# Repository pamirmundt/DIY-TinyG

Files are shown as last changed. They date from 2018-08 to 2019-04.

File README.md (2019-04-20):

# DIY TinyG
## DIY TinyG with Original Dimensions
This version has the original board dimensions and connector positions. 1206 package is selected for resistors and caps for easy hand soldering. Other than board dimensions and connector positions, rest of the components' positions are not exact.

- [X] Eagle Schmatic and Board File
- [ ] Bill of Materials
- [ ] Tested and Working

## DIY TinyG with Optimised Dimensions (100x100mm)
This version does **not** have the original board dimensions and connector positions. There is a relatively big price difference between *105x101mm* and *100x100mm* board dimensions at Seeed, OSH, JLCPCB and etc. So this version is a bit trimmed.

- [ ] Eagle Schmatic and Board File
- [ ] Bill of Materials
- [ ] Tested and Working

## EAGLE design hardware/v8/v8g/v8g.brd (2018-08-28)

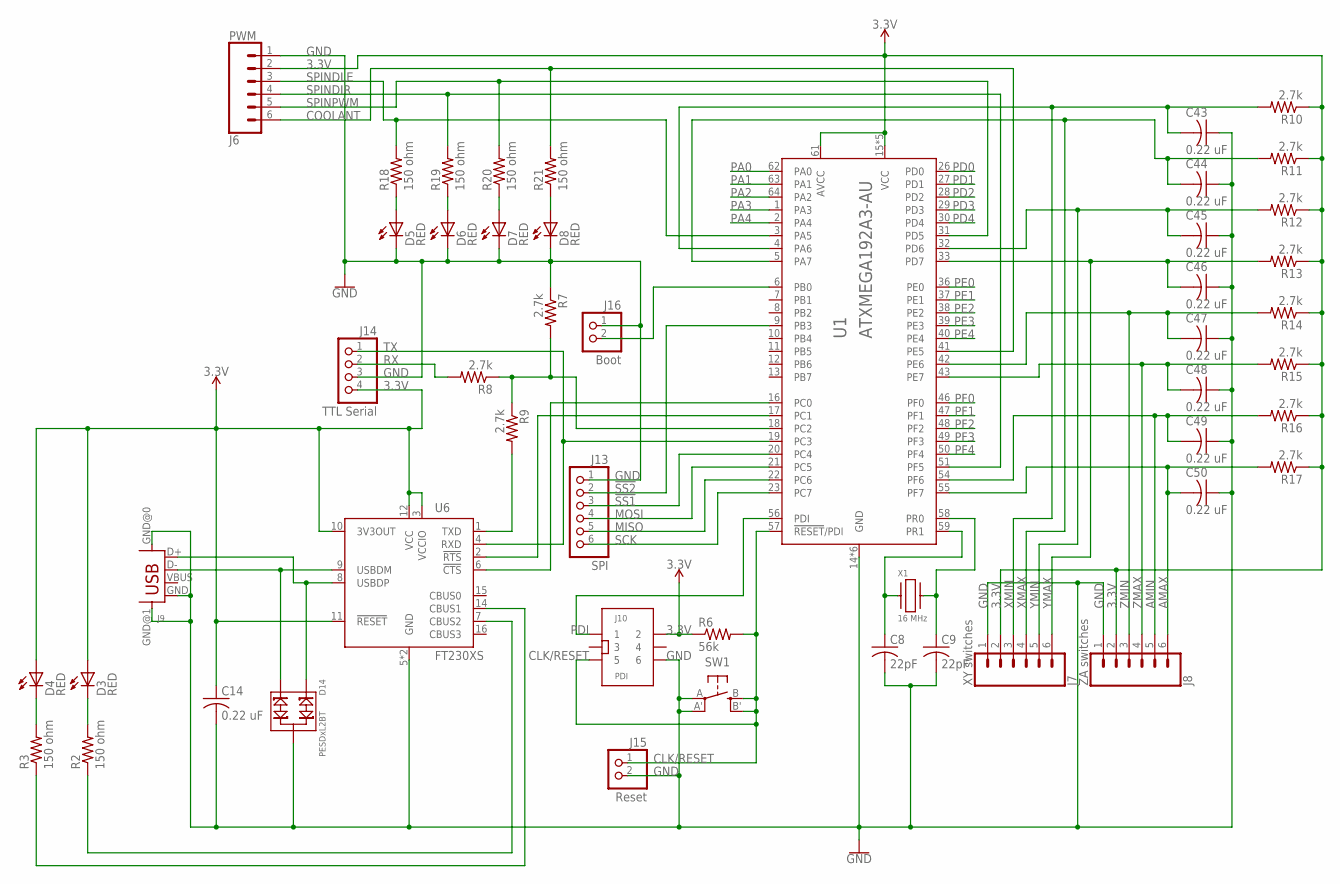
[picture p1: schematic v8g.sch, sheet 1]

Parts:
C8, C9: 22pF; C1206
C14, C43, C44, C45, C46, C47, C48, C49, C50: 0.22 uF; C1206
D3, D4, D5, D6, D7, D8: RED; CHIPLED_1206
D14: PESDxL2BT; SOT23
J6: PWM; SCREWTERMINAL-3.5MM-6
J7: XY switches; SCREWTERMINAL-3.5MM-6
J8: ZA switches; SCREWTERMINAL-3.5MM-6
J9: USB; USB-B-H
J10: PDI; IDC-6-PIN-61200621621
J13: SPI; 1X06
J14: TTL Serial; 1X04
J15: Reset; 1X02
J16: Boot; 1X02
R2, R3, R18, R19, R20, R21: 150 ohm; M1206
R6: 56k; M1206
R7, R8, R9, R10, R11, R12, R13, R14, R15, R16, R17: 2.7k; M1206
SW1: SPST_TACT-EVQQ2; EVQ-Q2
U1: ATXMEGA192A3-AU; TQFP-64A-64
U6: FT230XS; SSOP16
X1: 16 MHz; C4ST-SMD

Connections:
3.3V: C14.1, D3.A, D4.A, J6.2, J7.2, J8.2, J10.2, J14.4, R6.1, R10.1, R11.1, R12.1, R13.1, R14.1, R15.1, R16.1, R17.1, U1.15 (VCC), U1.25 (VCC), U1.35 (VCC), U1.45 (VCC), U1.53 (VCC), U1.61 (AVCC), U6.3 (VCCIO), U6.10 (3V3OUT), U6.11 (!RESET), U6.12 (VCC); also elsewhere on the board
!SS1: J13.3, U1.20 (PC4)
!SS2: J13.2, U1.9 (PB3)
AMAX: C50.2, J8.6, R17.2, U1.55 (PF7)
AMIN: C49.2, J8.5, R16.2, U1.54 (PF6)
CLK/RESET: J10.5, J15.1, R6.2, SW1.B (S), SW1.B' (S1), U1.57 (!RESET!/PDI)
COOLANT: J6.6, R21.2, U1.41 (PE5)
GND: C8.2, C9.2, C14.2, C43.1, C44.1, C45.1, C46.1, C47.1, C48.1, C49.1, C50.1, D5.C, D6.C, D7.C, D8.C, D14.3, J6.1, J7.1, J8.1, J9.GND, J9.GND@0 (GND), J9.GND@1 (GND), J10.6, J13.1, J14.3, J15.2, J16.1, R7.1, SW1.A, SW1.A' (P1), U1.14 (GND), U1.24 (GND), U1.34 (GND), U1.44 (GND), U1.52 (GND), U1.60 (GND), U6.5 (GND), U6.13 (GND); also elsewhere on the board
MISO: J13.5, U1.22 (PC6)
MOSI: J13.4, U1.21 (PC5)
unnamed: R9.2, U6.1 (TXD)
unnamed: D14.2, J9.D-, U6.9 (USBDM)
unnamed: R3.1, U6.14 (CBUS1)
unnamed: J16.2, U1.6 (PB0)
unnamed: D5.A, R18.1
unnamed: D6.A, R19.1
unnamed: D7.A, R20.1
unnamed: D8.A, R21.1
unnamed: R2.1, U6.7 (CBUS2)
unnamed: U1.16 (PC0), U6.6 (!CTS)
unnamed: U1.17 (PC1), U6.2 (!RTS)
unnamed: R7.2, R8.1, R9.1, U1.18 (PC2)
unnamed: D14.1, J9.D+, U6.8 (USBDP)
unnamed: D3.C, R2.2
unnamed: D4.C, R3.2
unnamed: C8.1, U1.59 (PR1), X1.1
unnamed: C9.1, U1.58 (PR0), X1.2
PA0: U1.62 (PA0); also elsewhere on the board
PA1: U1.63 (PA1); also elsewhere on the board
PA2: U1.64 (PA2); also elsewhere on the board
PA3: U1.1 (PA3); also elsewhere on the board
PA4: U1.2 (PA4); also elsewhere on the board
PD0: U1.26 (PD0); also elsewhere on the board
PD1: U1.27 (PD1); also elsewhere on the board
PD2: U1.28 (PD2); also elsewhere on the board
PD3: U1.29 (PD3); also elsewhere on the board
PD4: U1.30 (PD4); also elsewhere on the board
PDI: J10.1, U1.56 (PDI)
PE0: U1.36 (PE0); also elsewhere on the board
PE1: U1.37 (PE1); also elsewhere on the board
PE2: U1.38 (PE2); also elsewhere on the board
PE3: U1.39 (PE3); also elsewhere on the board
PE4: U1.40 (PE4); also elsewhere on the board
PF0: U1.46 (PF0); also elsewhere on the board
PF1: U1.47 (PF1); also elsewhere on the board
PF2: U1.48 (PF2); also elsewhere on the board
PF3: U1.49 (PF3); also elsewhere on the board
PF4: U1.50 (PF4); also elsewhere on the board
RX: J14.2, R8.2
SCK: J13.6, U1.23 (PC7)
SPINDIR: J6.4, R19.2, U1.51 (PF5)
SPINDLE: J6.3, R18.2, U1.3 (PA5)
SPINPWM: J6.5, R20.2, U1.31 (PD5)
TX: J14.1, U1.19 (PC3), U6.4 (RXD)
XMAX: C44.2, J7.4, R11.2, U1.5 (PA7)
XMIN: C43.2, J7.3, R10.2, U1.4 (PA6)
YMAX: C46.2, J7.6, R13.2, U1.33 (PD7)
YMIN: C45.2, J7.5, R12.2, U1.32 (PD6)
ZMAX: C48.2, J8.4, R15.2, U1.43 (PE7)
ZMIN: C47.2, J8.3, R14.2, U1.42 (PE6)

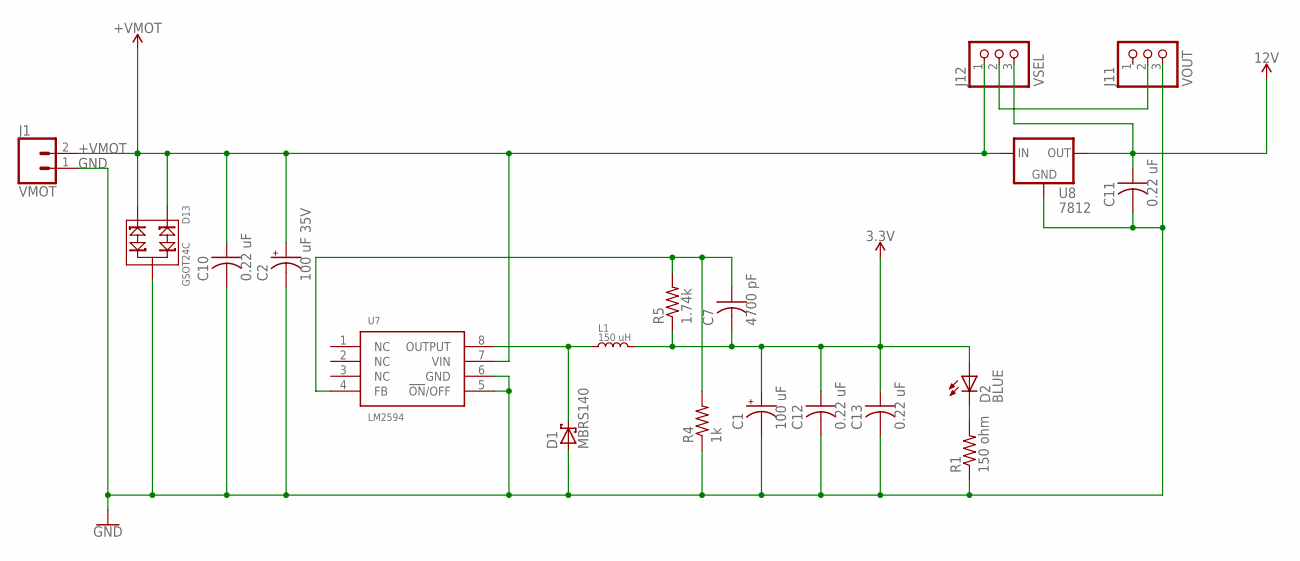
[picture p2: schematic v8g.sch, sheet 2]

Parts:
C1: 100 uF; WCAP-ASLI
C2: 100 uF 35V; WCAP-ASLI
C7: 4700 pF; C1206
C10, C11, C12, C13: 0.22 uF; C1206
D1: MBRS140; DO-214AA
D2: BLUE; CHIPLED_1206
D13: GSOT24C; SOT23
J1: VMOT; SCREWTERMINAL-5MM-2
J11: VOUT; 1X03
J12: VSEL; 1X03
L1: 150 uH; SDE0805A
R1: 150 ohm; R1206
R4: 1k; R1206
R5: 1.74k; R1206
U7: LM2594; SOIC-8_NB
U8: 7812; D2PAK

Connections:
3.3V: C1.+, C7.2, C12.1, C13.1, D2.A, L1.2, R5.1; also elsewhere on the board
12V: C11.1, J12.3, U8.3 (OUT)
+VMOT: C2.+, C10.1, D13.1, D13.2, J1.2, J12.1, U7.7 (VIN), U8.1 (IN); also elsewhere on the board
GND: C1.-, C2.-, C10.2, C11.2, C12.2, C13.2, D1.A, D13.3, J1.1, J11.3, R1.1, R4.1, U7.5 (!ON!/OFF), U7.6 (GND), U8.2 (GND); also elsewhere on the board
unnamed: D2.C, R1.2
unnamed: J11.2, J12.2
unnamed: D1.C, L1.1, U7.8 (OUTPUT)
unnamed: C7.1, R4.2, R5.2, U7.4 (FB)

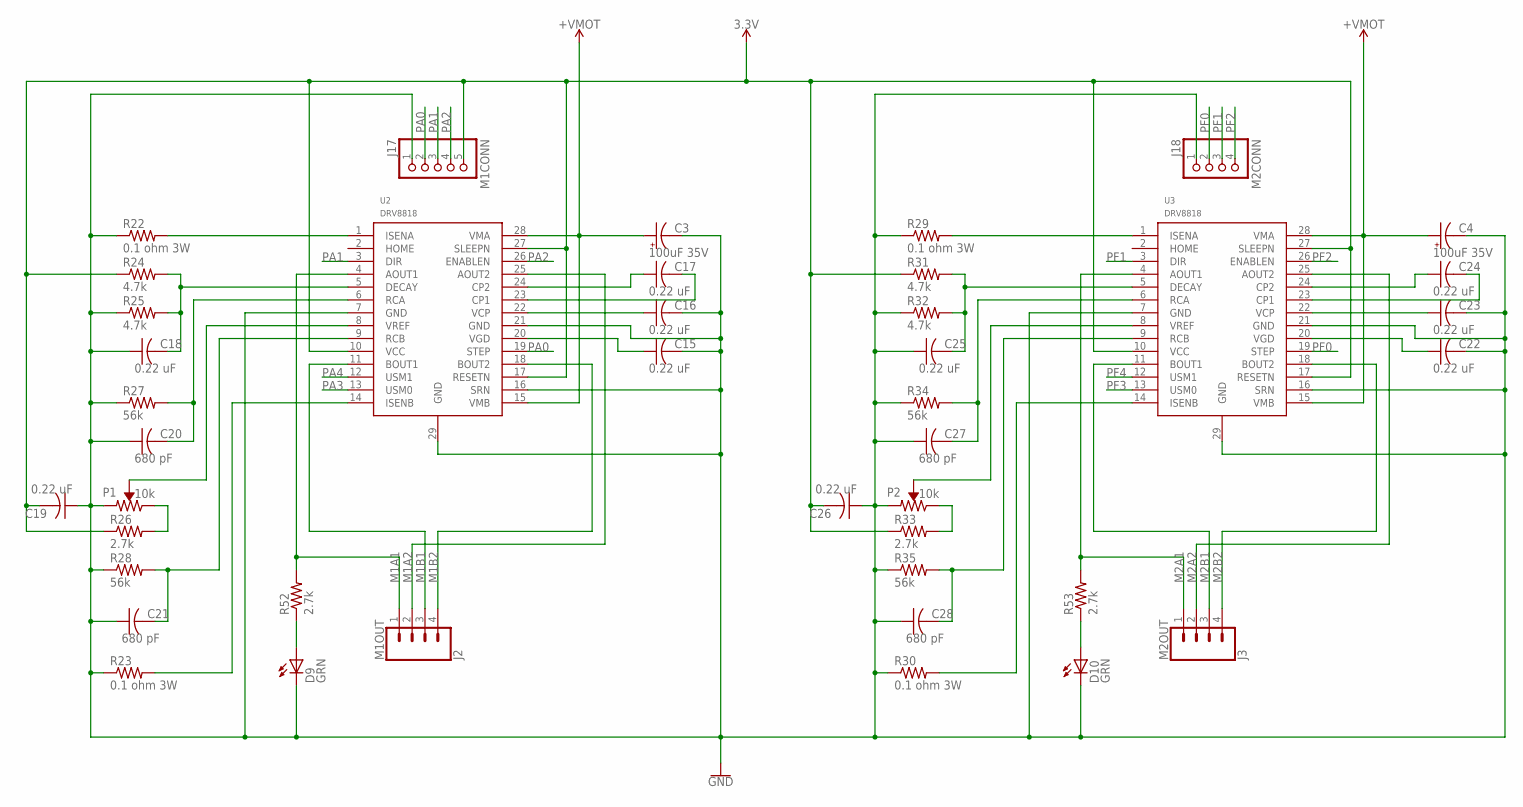
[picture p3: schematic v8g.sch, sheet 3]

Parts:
C3, C4: 100uF 35V; WCAP-ASLI
C15, C16, C17, C18, C19, C22, C23, C24, C25, C26: 0.22 uF; C1206
C20, C21, C27, C28: 680 pF; C1206
D9, D10: GRN; CHIPLED_1206
J2: M1OUT; SCREWTERMINAL-3.5MM-4
J3: M2OUT; SCREWTERMINAL-3.5MM-4
J17: M1CONN; 1X05
J18: M2CONN; 1X04
P1, P2: 10k; BOURNS_3361P
R22, R23, R29, R30: 0.1 ohm 3W; R2512
R24, R25, R31, R32: 4.7k; R1206
R26, R33: 2.7k; R1206
R27, R28, R34, R35: 56k; R1206
R52, R53: 2.7k; 0207/7
U2, U3: DRV8818; HTSSOP_28-PIN

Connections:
3.3V: C19.2, C26.2, J17.5, R24.1, R26.1, R31.1, R33.1, U2.10 (VCC), U2.17 (RESETN), U2.27 (SLEEPN), U3.10 (VCC), U3.17 (RESETN), U3.27 (SLEEPN); also elsewhere on the board
+VMOT: C3.+, C4.+, U2.15 (VMB), U2.28 (VMA), U3.15 (VMB), U3.28 (VMA); also elsewhere on the board
GND: C3.-, C4.-, C15.2, C16.2, C18.1, C19.1, C20.1, C21.1, C22.2, C23.2, C25.1, C26.1, C27.1, C28.1, D9.C, D10.C, J17.1, J18.1, P1.1, P2.1, R22.1, R23.1, R25.1, R27.1, R28.1, R29.1, R30.1, R32.1, R34.1, R35.1, U2.7 (GND), U2.16 (SRN), U2.21 (GND), U2.29 (GND), U3.7 (GND), U3.16 (SRN), U3.21 (GND), U3.29 (GND); also elsewhere on the board
M1A1: J2.1, R52.2, U2.4 (AOUT1)
M1A2: J2.2, U2.25 (AOUT2)
M1B1: J2.3, U2.11 (BOUT1)
M1B2: J2.4, U2.18 (BOUT2)
M2A1: J3.1, R53.2, U3.4 (AOUT1)
M2A2: J3.2, U3.25 (AOUT2)
M2B1: J3.3, U3.11 (BOUT1)
M2B2: J3.4, U3.18 (BOUT2)
unnamed: D9.A, R52.1
unnamed: R22.2, U2.1 (ISENA)
unnamed: P1.2, U2.8 (VREF)
unnamed: C17.1, U2.24 (CP2)
unnamed: P1.3, R26.2
unnamed: C17.2, U2.23 (CP1)
unnamed: C18.2, R24.2, R25.2, U2.5 (DECAY)
unnamed: C20.2, R27.2, U2.6 (RCA)
unnamed: C21.2, R28.2, U2.9 (RCB)
unnamed: R23.2, U2.14 (ISENB)
unnamed: C16.1, U2.22 (VCP)
unnamed: C15.1, U2.20 (VGD)
unnamed: R29.2, U3.1 (ISENA)
unnamed: C25.2, R31.2, R32.2, U3.5 (DECAY)
unnamed: C27.2, R34.2, U3.6 (RCA)
unnamed: P2.2, U3.8 (VREF)
unnamed: P2.3, R33.2
unnamed: C28.2, R35.2, U3.9 (RCB)
unnamed: R30.2, U3.14 (ISENB)
unnamed: D10.A, R53.1
unnamed: C24.2, U3.23 (CP1)
unnamed: C23.1, U3.22 (VCP)
unnamed: C22.1, U3.20 (VGD)
unnamed: C24.1, U3.24 (CP2)
PA0: J17.2, U2.19 (STEP); also elsewhere on the board
PA1: J17.3, U2.3 (DIR); also elsewhere on the board
PA2: J17.4, U2.26 (ENABLEN); also elsewhere on the board
PA3: U2.13 (USM0); also elsewhere on the board
PA4: U2.12 (USM1); also elsewhere on the board
PF0: J18.2, U3.19 (STEP); also elsewhere on the board
PF1: J18.3, U3.3 (DIR); also elsewhere on the board
PF2: J18.4, U3.26 (ENABLEN); also elsewhere on the board
PF3: U3.13 (USM0); also elsewhere on the board
PF4: U3.12 (USM1); also elsewhere on the board

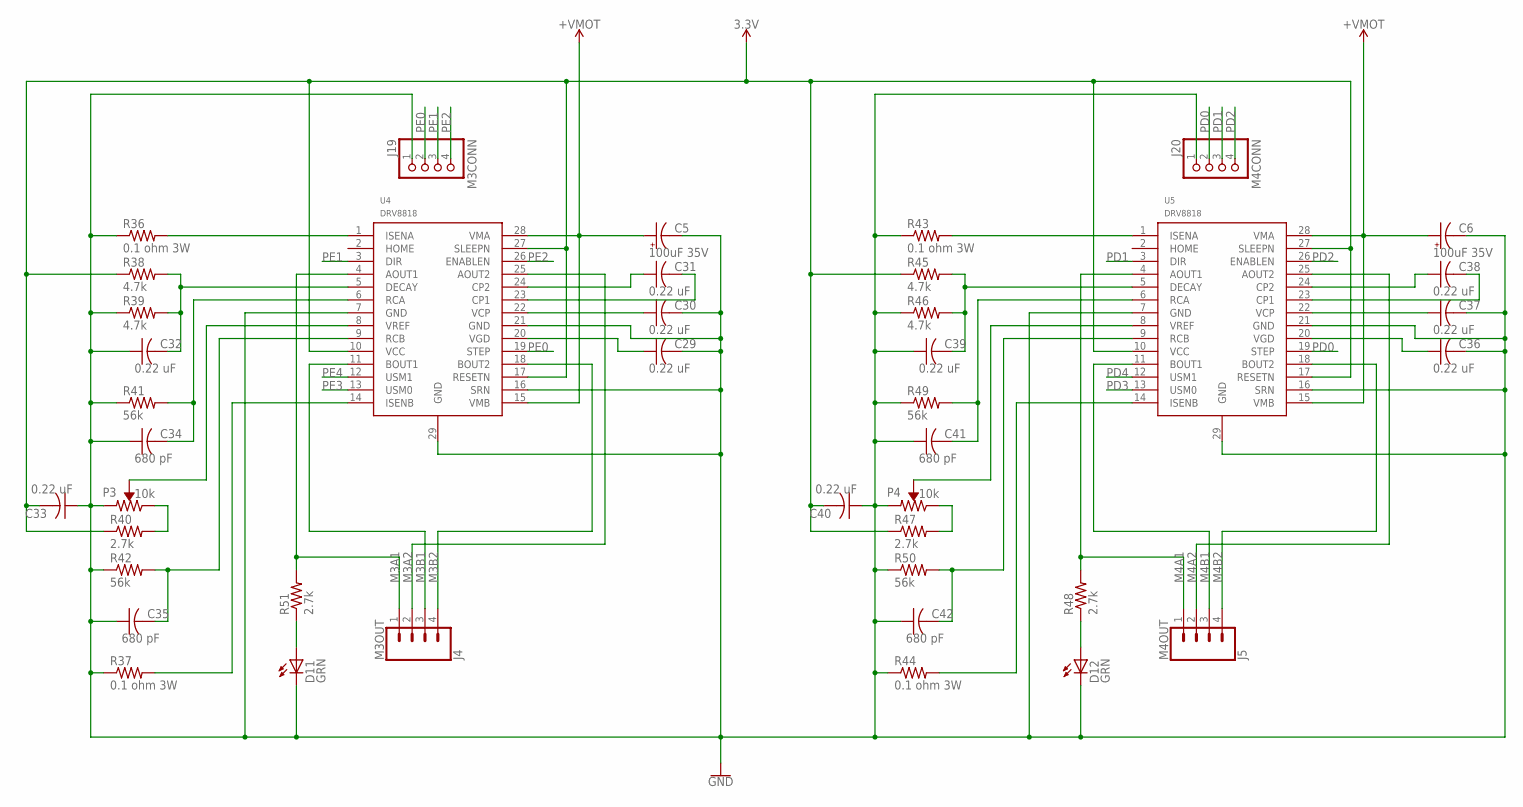
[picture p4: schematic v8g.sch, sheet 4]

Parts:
C5, C6: 100uF 35V; WCAP-ASLI
C29, C30, C31, C32, C33, C36, C37, C38, C39, C40: 0.22 uF; C1206
C34, C35, C41, C42: 680 pF; C1206
D11, D12: GRN; CHIPLED_1206
J4: M3OUT; SCREWTERMINAL-3.5MM-4
J5: M4OUT; SCREWTERMINAL-3.5MM-4
J19: M3CONN; 1X04
J20: M4CONN; 1X04
P3, P4: 10k; BOURNS_3361P
R36, R37, R43, R44: 0.1 ohm 3W; R2512
R38, R39, R45, R46: 4.7k; R1206
R40, R47: 2.7k; R1206
R41, R42, R49, R50: 56k; R1206
R48, R51: 2.7k; 0207/7
U4, U5: DRV8818; HTSSOP_28-PIN

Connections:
3.3V: C33.2, C40.2, R38.1, R40.1, R45.1, R47.1, U4.10 (VCC), U4.17 (RESETN), U4.27 (SLEEPN), U5.10 (VCC), U5.17 (RESETN), U5.27 (SLEEPN); also elsewhere on the board
+VMOT: C5.+, C6.+, U4.15 (VMB), U4.28 (VMA), U5.15 (VMB), U5.28 (VMA); also elsewhere on the board
GND: C5.-, C6.-, C29.2, C30.2, C32.1, C33.1, C34.1, C35.1, C36.2, C37.2, C39.1, C40.1, C41.1, C42.1, D11.C, D12.C, J19.1, J20.1, P3.1, P4.1, R36.1, R37.1, R39.1, R41.1, R42.1, R43.1, R44.1, R46.1, R49.1, R50.1, U4.7 (GND), U4.16 (SRN), U4.21 (GND), U4.29 (GND), U5.7 (GND), U5.16 (SRN), U5.21 (GND), U5.29 (GND); also elsewhere on the board
M3A1: J4.1, R51.2, U4.4 (AOUT1)
M3A2: J4.2, U4.25 (AOUT2)
M3B1: J4.3, U4.11 (BOUT1)
M3B2: J4.4, U4.18 (BOUT2)
M4A1: J5.1, R48.2, U5.4 (AOUT1)
M4A2: J5.2, U5.25 (AOUT2)
M4B1: J5.3, U5.11 (BOUT1)
M4B2: J5.4, U5.18 (BOUT2)
unnamed: R36.2, U4.1 (ISENA)
unnamed: C32.2, R38.2, R39.2, U4.5 (DECAY)
unnamed: C34.2, R41.2, U4.6 (RCA)
unnamed: P3.2, U4.8 (VREF)
unnamed: P3.3, R40.2
unnamed: C35.2, R42.2, U4.9 (RCB)
unnamed: R37.2, U4.14 (ISENB)
unnamed: D11.A, R51.1
unnamed: C31.2, U4.23 (CP1)
unnamed: C30.1, U4.22 (VCP)
unnamed: C29.1, U4.20 (VGD)
unnamed: C31.1, U4.24 (CP2)
unnamed: R43.2, U5.1 (ISENA)
unnamed: C39.2, R45.2, R46.2, U5.5 (DECAY)
unnamed: C41.2, R49.2, U5.6 (RCA)
unnamed: P4.2, U5.8 (VREF)
unnamed: P4.3, R47.2
unnamed: C42.2, R50.2, U5.9 (RCB)
unnamed: R44.2, U5.14 (ISENB)
unnamed: D12.A, R48.1
unnamed: C38.2, U5.23 (CP1)
unnamed: C37.1, U5.22 (VCP)
unnamed: C36.1, U5.20 (VGD)
unnamed: C38.1, U5.24 (CP2)
PD0: J20.2, U5.19 (STEP); also elsewhere on the board
PD1: J20.3, U5.3 (DIR); also elsewhere on the board
PD2: J20.4, U5.26 (ENABLEN); also elsewhere on the board
PD3: U5.13 (USM0); also elsewhere on the board
PD4: U5.12 (USM1); also elsewhere on the board
PE0: J19.2, U4.19 (STEP); also elsewhere on the board
PE1: J19.3, U4.3 (DIR); also elsewhere on the board
PE2: J19.4, U4.26 (ENABLEN); also elsewhere on the board
PE3: U4.13 (USM0); also elsewhere on the board
PE4: U4.12 (USM1); also elsewhere on the board

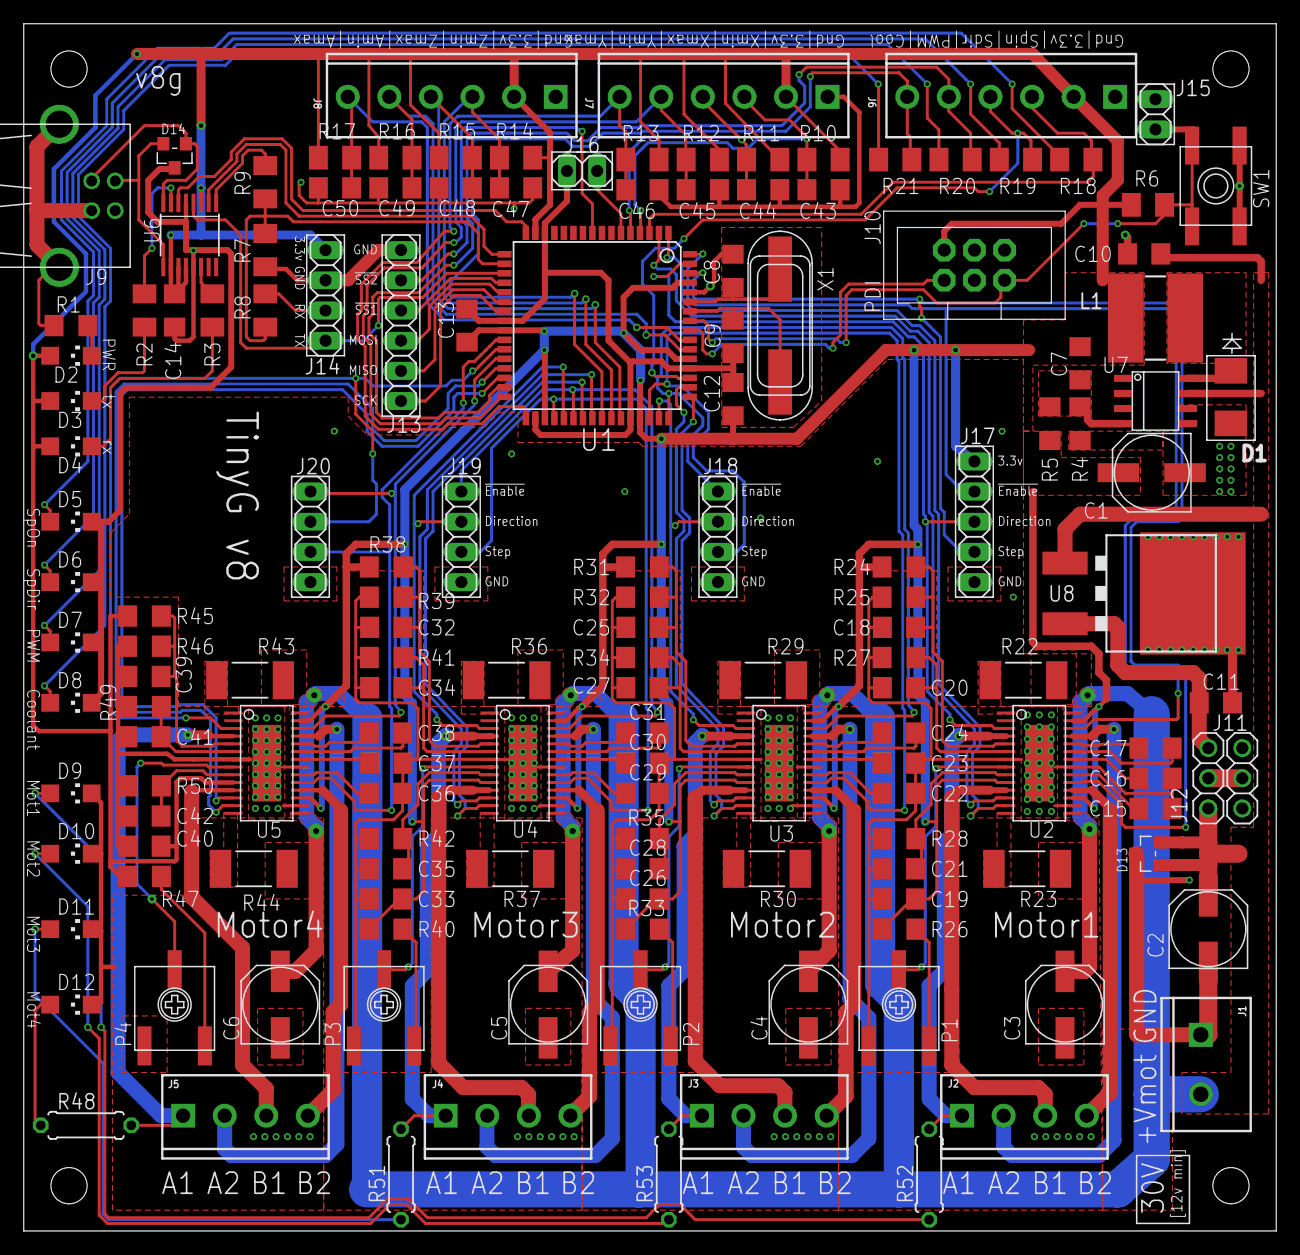
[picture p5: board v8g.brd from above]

Board: 2 copper layers, 105.4 x 101.6 mm, 152 parts (0 on the bottom side), 130 nets.

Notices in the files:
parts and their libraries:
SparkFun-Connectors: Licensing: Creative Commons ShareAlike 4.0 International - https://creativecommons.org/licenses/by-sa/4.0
